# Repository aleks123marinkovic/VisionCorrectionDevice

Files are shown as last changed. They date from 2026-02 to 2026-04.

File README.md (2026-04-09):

# Vision Corrector

Holds SolidWorks, STL, .3mf, .STEP, and related files for the Head Coil-Mounted Vision Correction Device for Magnetic Resonance Imaging.

First, if you don't have a slicer, download the latest version of OrcaSlicer by following the ReadMe for your system: https://github.com/SoftFever/OrcaSlicer?tab=readme-ov-file 

Download the .3mf file of the vision corrector and open it in your preferred slicer or OrcaSlicer.

Adjust the settings for the layer height to be 0.08 mm or as close to 0.08 mm as possbile. The Bambu X1 Series goes down to 0.08 mm, which we found works very well.

Adjust wall loops to 5 and infill to 30-40%.

Only activate supports for the lens holder tops and the mount.

Once the 3D prints are complete, please refer to the following videos.

How to place gels:
https://youtu.be/AsIwOQPe71k

How to assemble the bolts:
https://youtu.be/D7gqrahNJ6g

How to assemble the device:
https://youtu.be/XtZz5X_WPjU

How to place lenses:
https://youtu.be/qEZhaU0NNYg

# Citation
If you compare with, build on, or use aspects of the Vision Corrector work, please cite the following:

```bibtex
@misc{marinkovic_head_2026,
	title = {Head Coil-Mounted Vision Correction Device for Magnetic Resonance Imaging},
	url = {http://arxiv.org/abs/2604.04966},
	doi = {10.48550/arXiv.2604.04966},
	number = {{arXiv}:2604.04966},
	publisher = {{arXiv}},
	author = {Marinkovic, Aleksandar and Tyszka, Julian Michael},
	date = {2026-04-04},
	eprinttype = {arxiv},
	eprint = {2604.04966 [physics]},
	keywords = {Physics - Instrumentation and Detectors, Physics - Medical Physics},
}
```

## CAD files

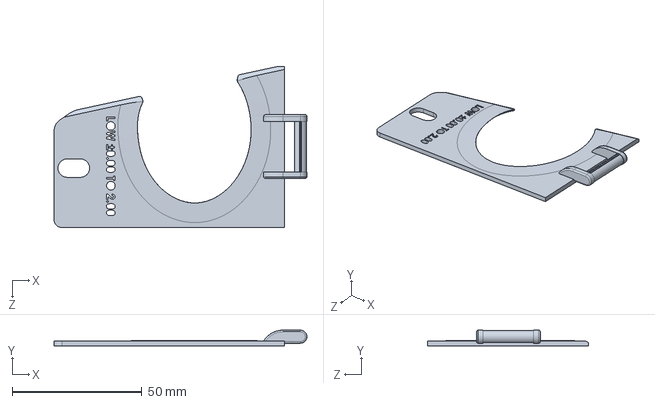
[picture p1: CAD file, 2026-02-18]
Part_Files/Lens_Holder_Parts/Lens_Holder_Left_Low.SLDPRT
97.4 x 6.10 x 62.0 mm

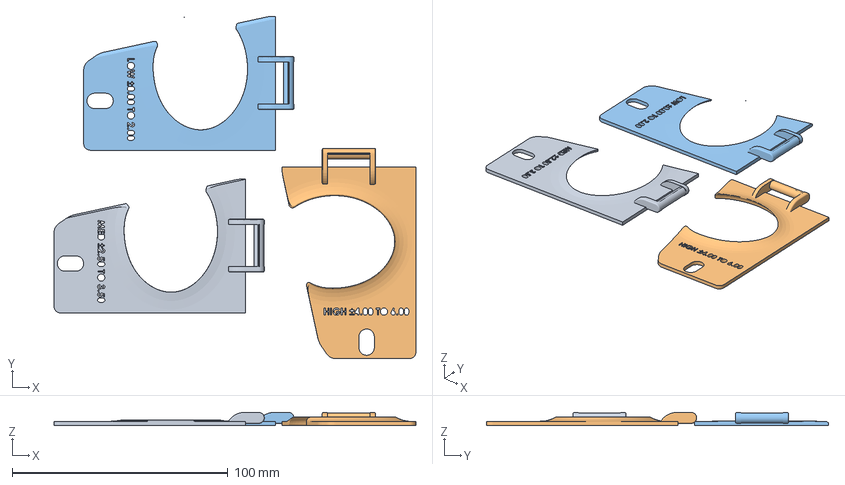
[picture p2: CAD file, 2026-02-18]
Print_Files/3mf_Files/Lens_Holders_Left.3mf
167.6 x 158.5 x 6.10 mm
Lens_Holder_Left_Med.STL_2
Lens_Holder_Left_High.STL_2
Lens_Holder_Left_Low.STL_2
Lens_Holder_Left_Low.STL_3

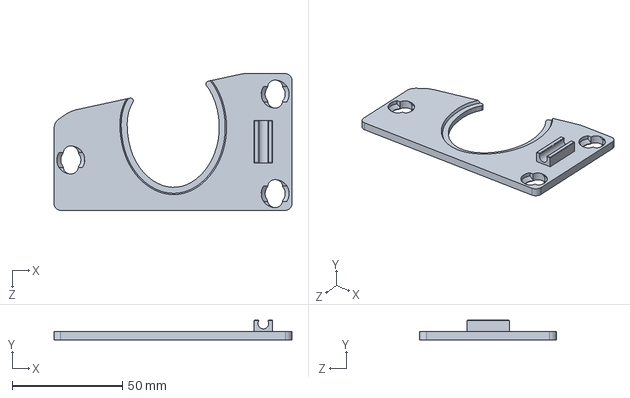
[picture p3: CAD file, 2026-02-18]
Part_Files/Lens_Holder_Parts/Lens_Holder_Left_Bottom.SLDPRT
107.8 x 8.89 x 62.0 mm

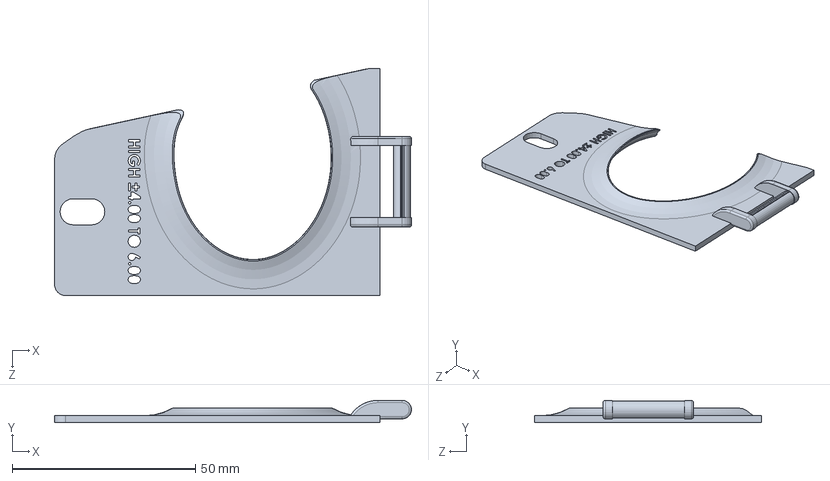
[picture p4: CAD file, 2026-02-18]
Part_Files/Lens_Holder_Parts/Lens_Holder_Left_High.SLDPRT
97.4 x 6.10 x 62.0 mm

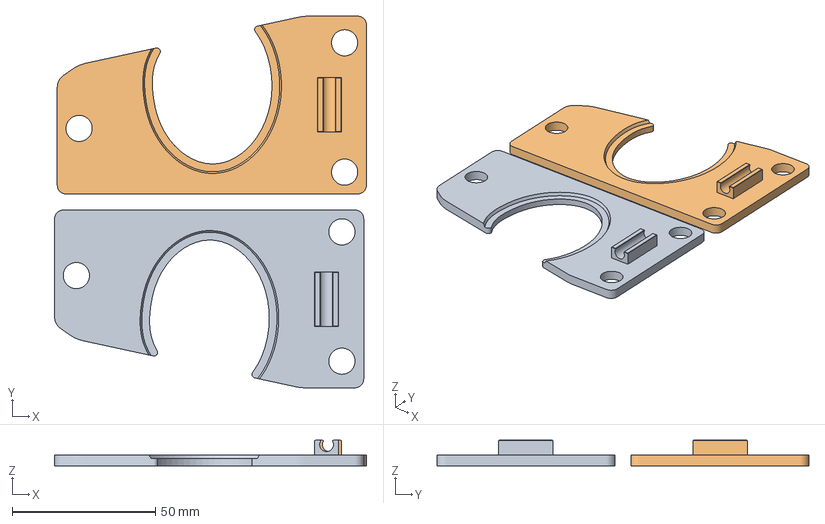
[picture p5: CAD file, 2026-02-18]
Print_Files/3mf_Files/Lens_Holder_Bottoms.3mf
108.8 x 129.6 x 8.89 mm
Lens_Holder_Right_Bottom.STL
Lens_Holder_Left_Bottom.STL

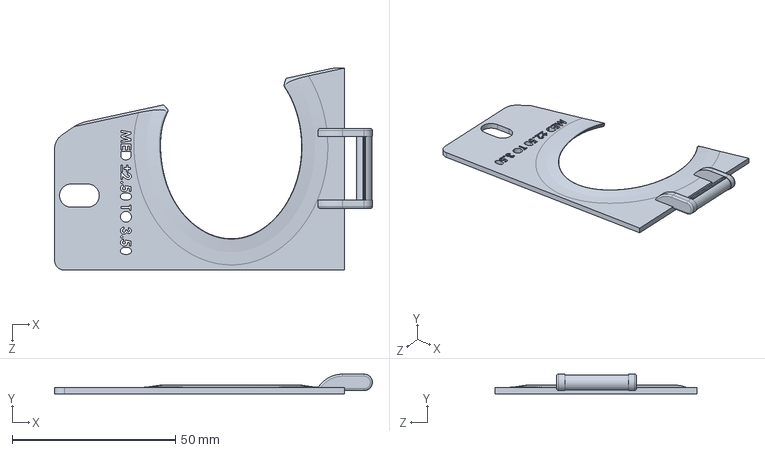
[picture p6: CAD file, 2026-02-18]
Part_Files/Lens_Holder_Parts/Lens_Holder_Left_Med.SLDPRT
97.4 x 6.10 x 62.0 mm

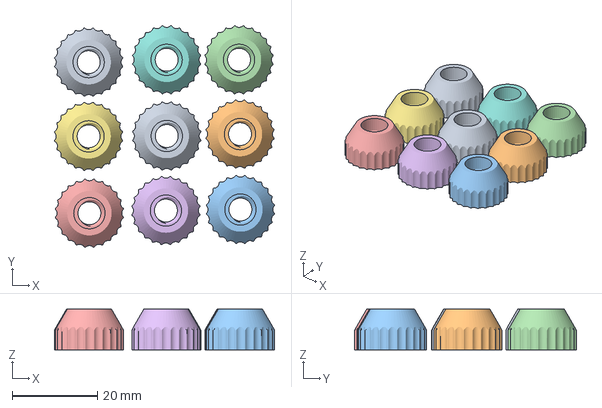
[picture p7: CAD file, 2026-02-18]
Print_Files/3mf_Files/Nuts.3mf
51.7 x 52.1 x 9.53 mm
Nut.STL x 9

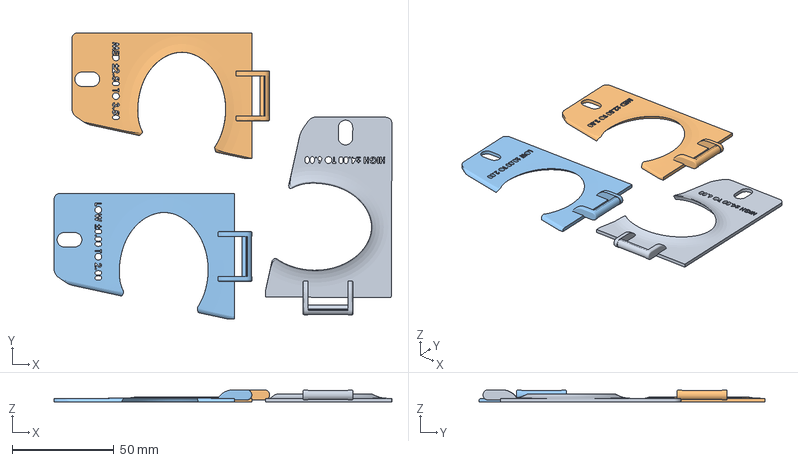
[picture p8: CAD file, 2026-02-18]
Print_Files/3mf_Files/Lens_Holders_Right.3mf
166.4 x 141.0 x 6.10 mm
Lens_Holder_Right_High.STL_1
Lens_Holder_Right_Med.STL_1
Lens_Holder_Right_Low.STL_2

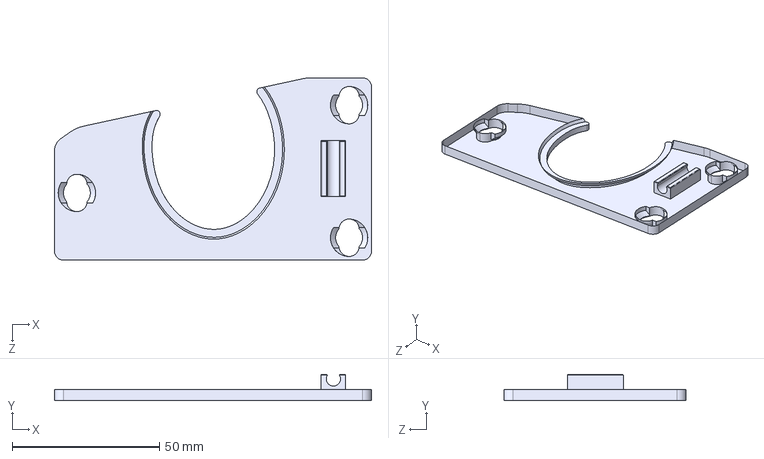
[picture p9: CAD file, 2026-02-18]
Print_Files/STEP_Files/Lens_Holder_Left_Bottom.STEP
107.8 x 8.89 x 62.0 mm

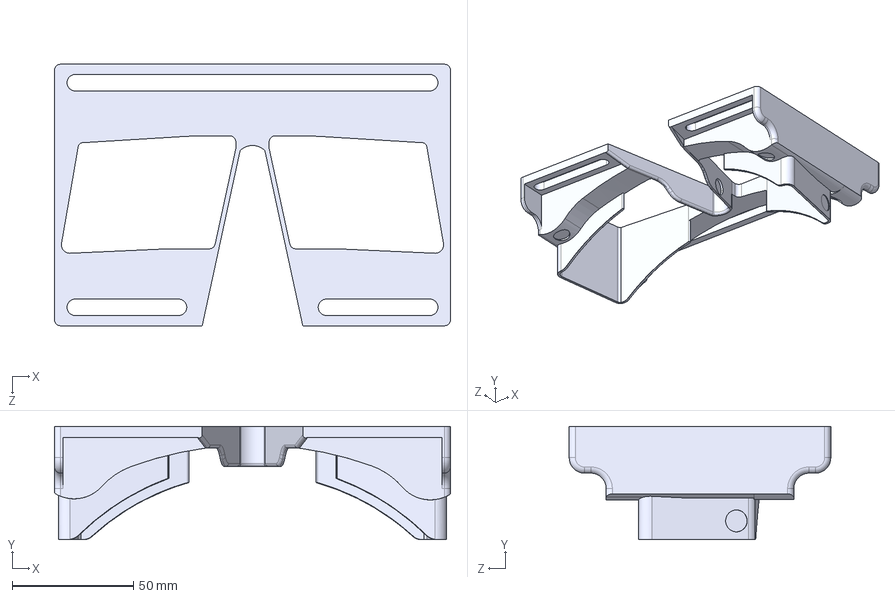
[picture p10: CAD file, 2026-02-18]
Print_Files/STEP_Files/Mount.STEP
163.2 x 46.7 x 107.8 mm

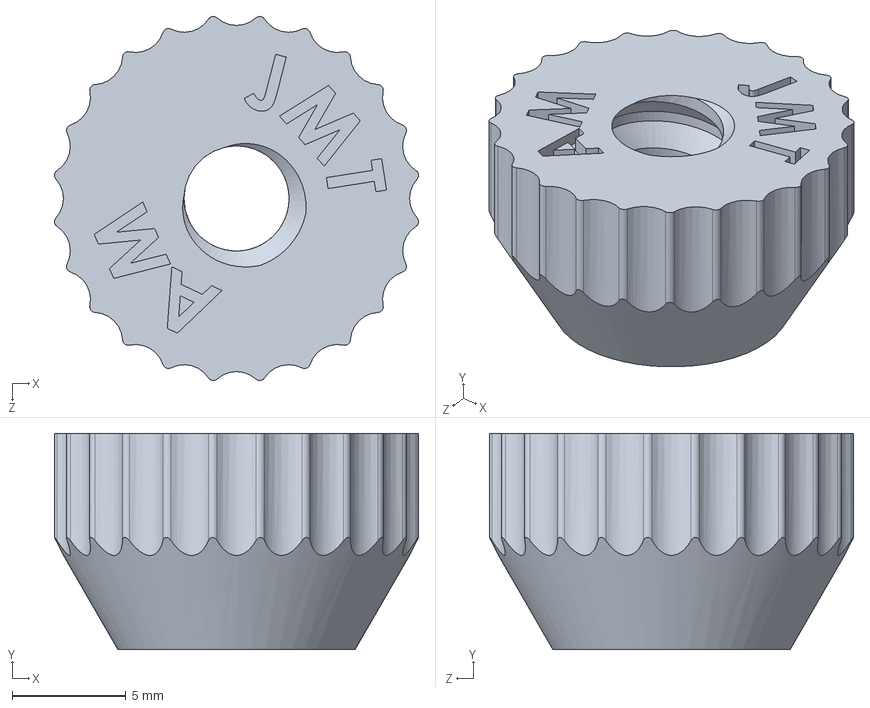
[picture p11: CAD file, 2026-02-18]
Part_Files/Nut_And_Bolt_And_Washer_Parts/Nut.SLDPRT
16.0 x 9.53 x 16.0 mm

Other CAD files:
Print_Files/STEP_Files/Lens_Holder_Left_Low.STEP
Print_Files/STEP_Files/Lens_Holder_Right_Low.STEP
Print_Files/STEP_Files/Lens_Holder_Right_High.STEP
Print_Files/STEP_Files/Lens_Holder_Left_High.STEP
Print_Files/STEP_Files/Lens_Holder_Right_Med.STEP
Print_Files/STEP_Files/Lens_Holder_Left_Med.STEP
Print_Files/STEP_Files/Lens_Holder_Right_Bottom.STEP
Part_Files/Nut_And_Bolt_And_Washer_Parts/Bolt.SLDPRT
Part_Files/Nut_And_Bolt_And_Washer_Parts/Supporting_Washer.SLDPRT
Print_Files/3mf_Files/Bolts.3mf
Print_Files/3mf_Files/Mount.3mf
Print_Files/3mf_Files/Supporting_Washer.3mf
Print_Files/STEP_Files/Bolt.STEP
Print_Files/STEP_Files/Nut.STEP
Print_Files/STEP_Files/Supporting_Washer.STEP
Print_Files/STL_Files/Bolt.STL
Print_Files/STL_Files/Lens_Holder_Left_Bottom.STL
Print_Files/STL_Files/Lens_Holder_Left_High.STL
Print_Files/STL_Files/Lens_Holder_Left_Low.STL
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

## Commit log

2026-02-18 Revise README for Vision Corrector device
2026-02-18 Added All Print and Design Files
    [Bolt.SLDPRT, Bolt.STEP, Bolt.STL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]
2026-04-09 Added citation info in README
    Added citation for the Head Coil-Mounted Vision Correction Device paper.
